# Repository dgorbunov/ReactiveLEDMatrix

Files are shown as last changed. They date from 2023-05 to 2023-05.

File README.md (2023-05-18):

# Reactive LED Matrix
An expandable matrix of addressable WS2812B RGB LEDs, made interactive through an array of high-power infrared LEDs and phototransistors. Panels can be plugged into other panels for large array sizes, and can be externally controlled via an ESP32 and custom React app. Final Project for UMass Amherst CICS 256, Make: Physical Computing.

### Photos
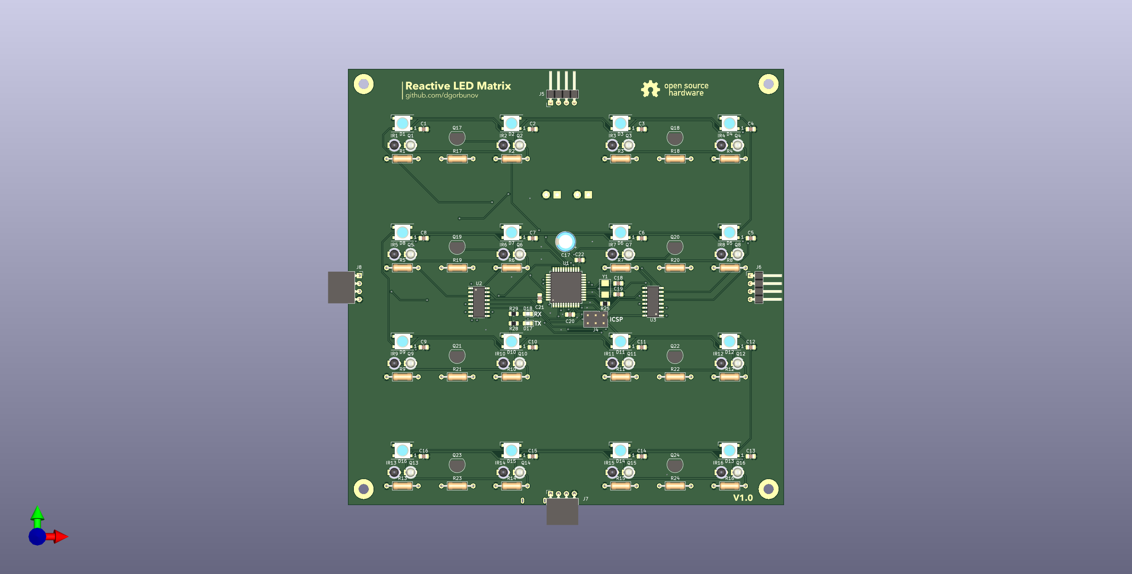
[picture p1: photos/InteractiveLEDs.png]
Board Render

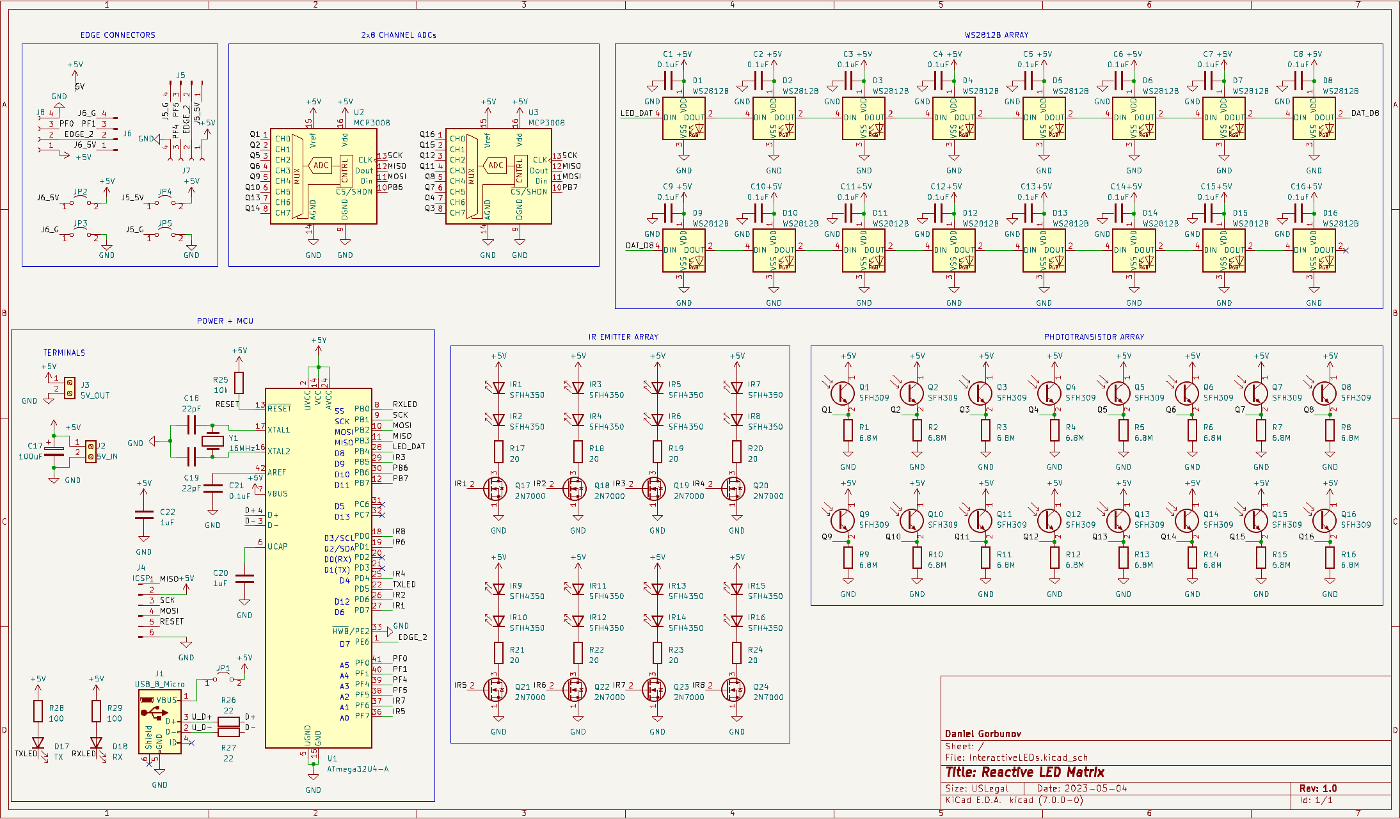
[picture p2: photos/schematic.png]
Schematic Image

## Hardware
Each panel is controlled by an ATMega32u4 microcontroller (compiling for Arduino Leonardo), along with two MCP3008 8 channel 10-bit ADCs for reading phototransistor voltages. The high-power infrared LEDs can sink up to 100mA, so each pair of IR LEDs is switched on through an N-Channel MOSFET for several microseconds and corresponding phototransistor output read. The edge connectors use UART to send data to up to four neighboring panels and thus propagate matrix effects across multiple panels.

Each tile of the matrix measures 140mm x 140mm with 35mm pitch between the WS2812B LEDs and 130mm between the mounting holes, which are M3.

### Build it Yourself
The BOM, Schematic, and Gerbers can be found [here](https://github.com/dgorbunov/ReactiveLEDMatrix/tree/main/hardware).
The DigiKey parts list can be found [here](https://www.digikey.com/en/mylists/list/SEOYTBGGIW)

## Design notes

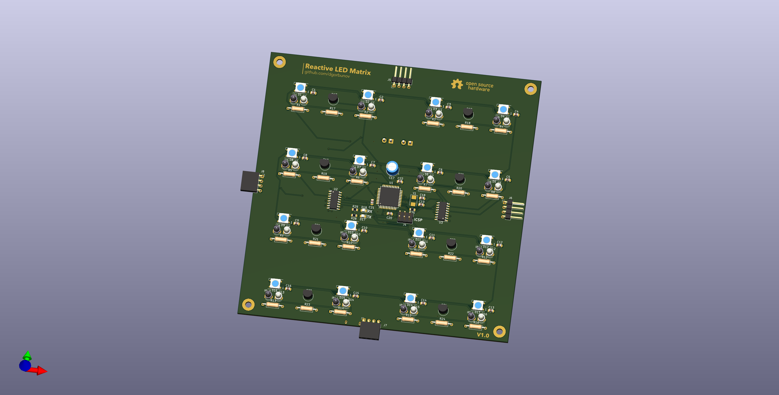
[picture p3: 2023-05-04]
photos/InteractiveLEDsSide.png

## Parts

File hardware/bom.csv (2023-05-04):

Comment | Designator | Footprint | LCSC
0.1uF | C1,C2,C3,C4,C5,C6,C7,C8,C9,C10,C11,C12,C13,C14,C15,C16,C21 | Capacitor_SMD:C_0805_2012Metric_Pad1.18x1.45mm_HandSolder
100uF | C17 | Capacitor_THT:CP_Radial_D6.3mm_P2.50mm
22pF | C18,C19 | Capacitor_SMD:C_0805_2012Metric_Pad1.18x1.45mm_HandSolder
1uF | C20,C22 | Capacitor_SMD:C_0805_2012Metric_Pad1.18x1.45mm_HandSolder
WS2812B | D1,D2,D3,D4,D5,D6,D7,D8,D9,D10,D11,D12,D13,D14,D15,D16 | LED_SMD:LED_WS2812B_PLCC4_5.0x5.0mm_P3.2mm
TX | D17 | LED_SMD:LED_0805_2012Metric_Pad1.15x1.40mm_HandSolder
RX | D18 | LED_SMD:LED_0805_2012Metric_Pad1.15x1.40mm_HandSolder
SFH4350 | IR1,IR2,IR3,IR4,IR5,IR6,IR7,IR8,IR9,IR10,IR11,IR12,IR13,IR14,IR15,IR16 | LED_THT:LED_D3.0mm_IRGrey
USB_B_Micro | J1 | Connector_USB:USB_Micro-B_GCT_USB3076-30-A
5V_IN | J2 | TerminalBlock_Phoenix:TerminalBlock_Phoenix_PT-1,5-2-3.5-H_1x02_P3.50mm_Horizontal
5V_OUT | J3 | TerminalBlock_Phoenix:TerminalBlock_Phoenix_PT-1,5-2-3.5-H_1x02_P3.50mm_Horizontal
ICSP | J4 | Connector_PinHeader_2.54mm:PinHeader_2x03_P2.54mm_Vertical
Conn_01x04_Pin | J5,J6 | Connector_PinHeader_2.54mm:PinHeader_1x04_P2.54mm_Horizontal
Conn_01x04_Socket | J7,J8 | Connector_PinSocket_2.54mm:PinSocket_1x04_P2.54mm_Horizontal
Jumper_2_Open | JP1,JP2,JP3,JP4,JP5 | Jumper:SolderJumper-2_P1.3mm_Open_TrianglePad1.0x1.5mm
SFH309 | Q1,Q2,Q3,Q4,Q5,Q6,Q7,Q8,Q9,Q10,Q11,Q12,Q13,Q14,Q15,Q16 | LED_THT:LED_D3.0mm_Clear
2N7000 | Q17,Q18,Q19,Q20,Q21,Q22,Q23,Q24 | Package_TO_SOT_THT:TO-92_Inline
10k | R1,R2,R3,R4,R5,R6,R7,R8,R9,R10,R11,R12,R13,R14,R15,R16 | Resistor_THT:R_Axial_DIN0207_L6.3mm_D2.5mm_P10.16mm_Horizontal
20 | R17,R18,R19,R20,R21,R22,R23,R24 | Resistor_THT:R_Axial_DIN0207_L6.3mm_D2.5mm_P10.16mm_Horizontal
10k | R25 | Resistor_SMD:R_0805_2012Metric_Pad1.20x1.40mm_HandSolder
22 | R26,R27 | Resistor_SMD:R_0805_2012Metric_Pad1.20x1.40mm_HandSolder
100 | R28,R29 | Resistor_SMD:R_0805_2012Metric_Pad1.20x1.40mm_HandSolder
ATmega32U4-A | U1 | Package_QFP:TQFP-44_10x10mm_P0.8mm
MCP3008 | U2,U3 | Package_SO:SOIC-16_3.9x9.9mm_P1.27mm
16MHz | Y1 | Crystal:Crystal_SMD_5032-2Pin_5.0x3.2mm

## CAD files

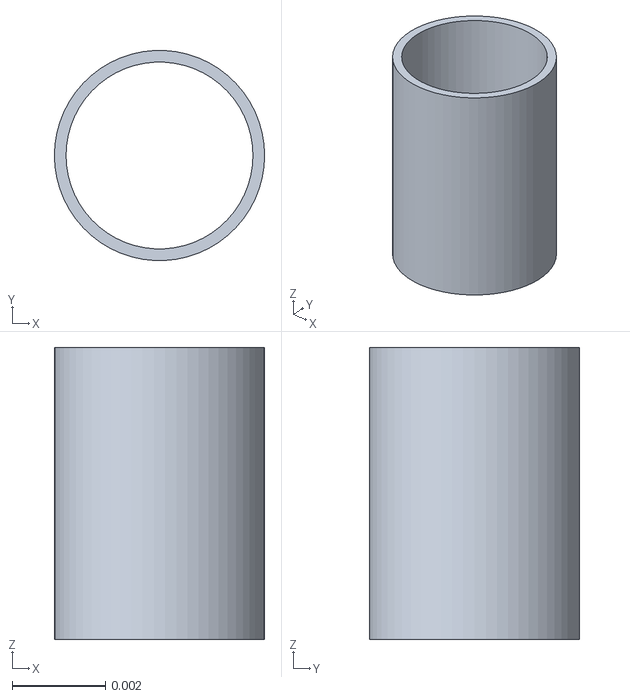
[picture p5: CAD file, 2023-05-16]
hardware/QShield.stl
0.0045 x 0.00449 x 0.00625

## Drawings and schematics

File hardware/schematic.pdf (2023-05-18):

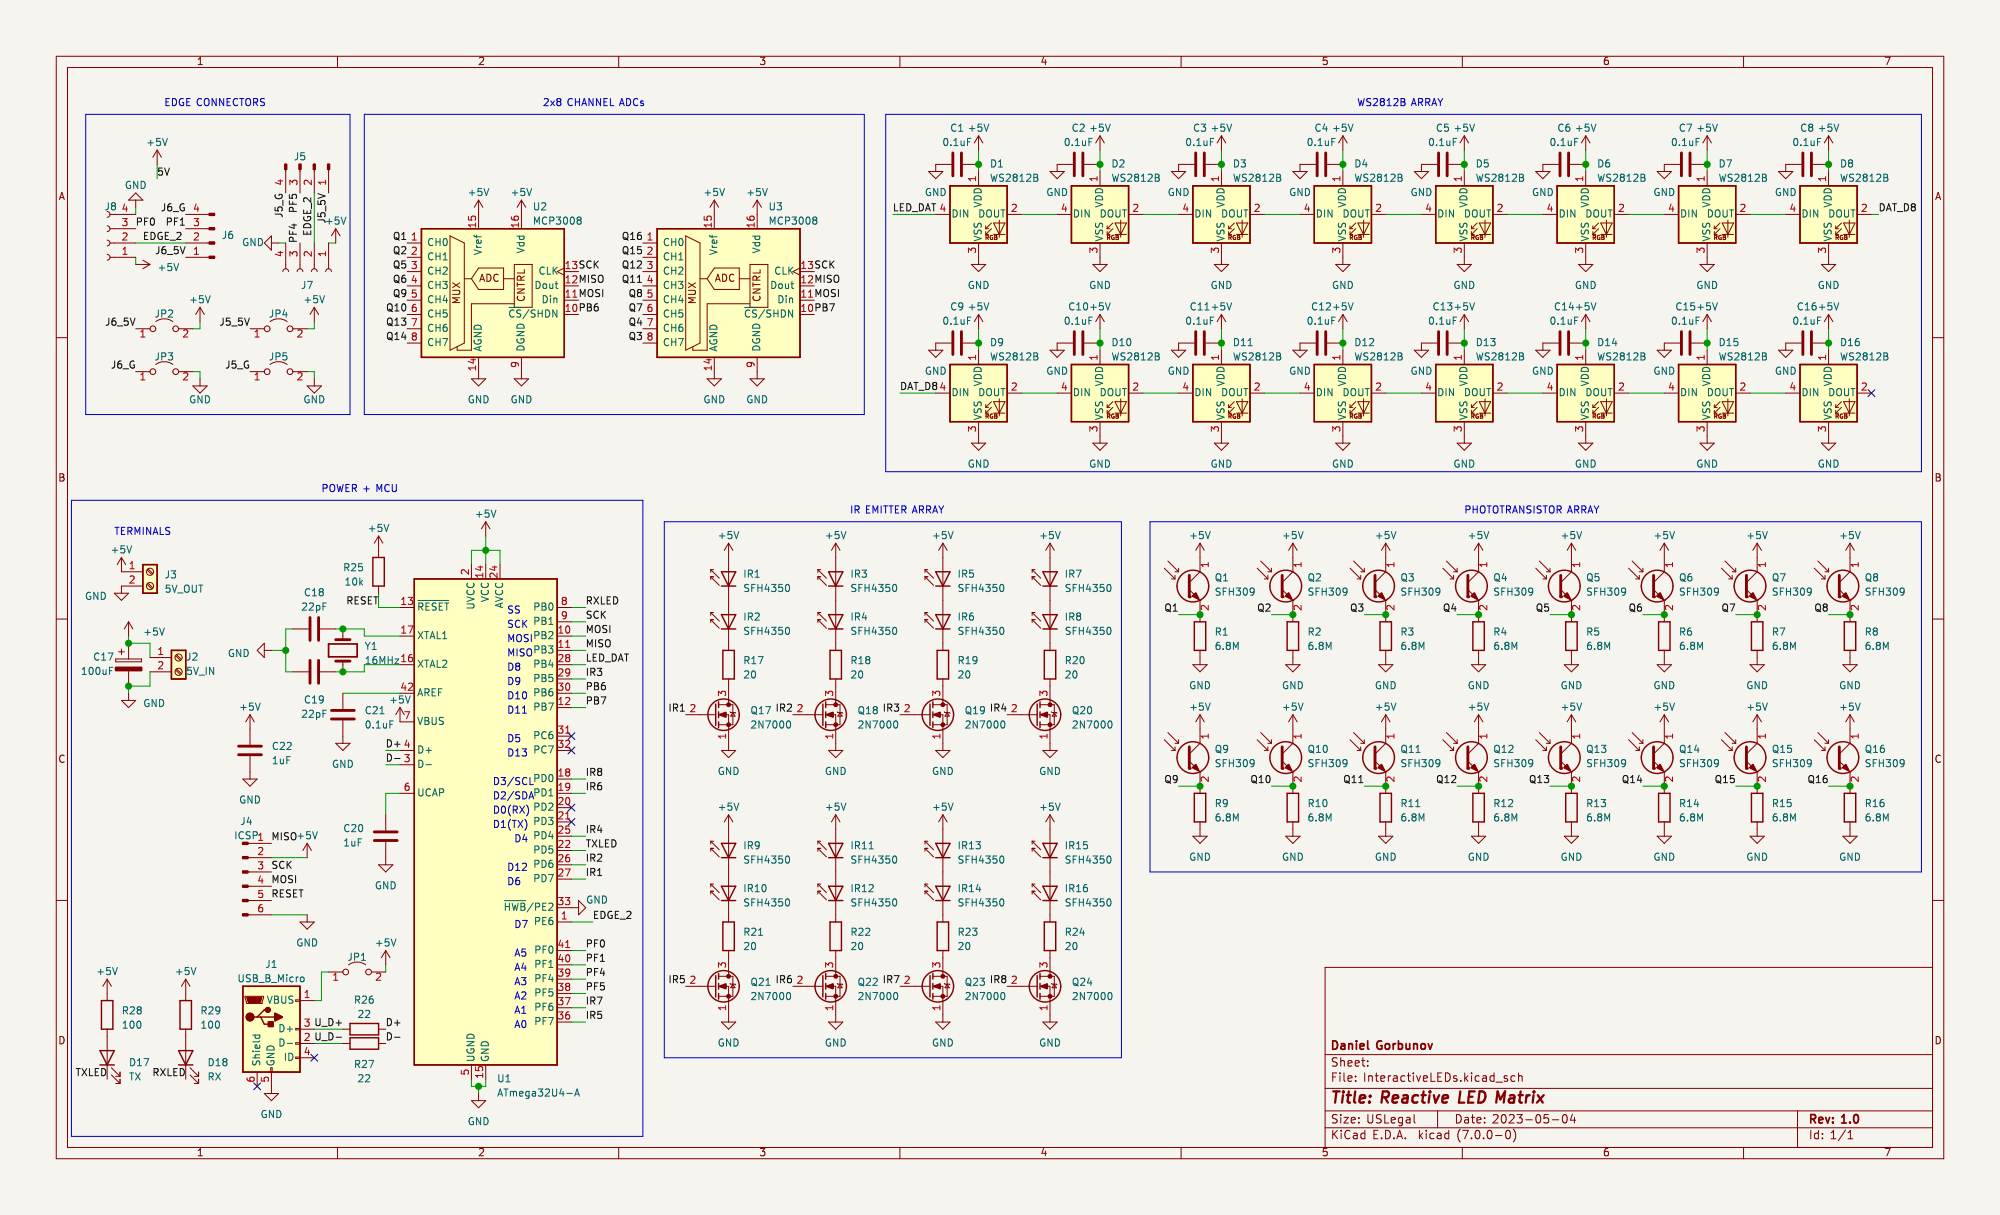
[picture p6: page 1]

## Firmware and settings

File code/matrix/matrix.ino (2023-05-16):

#include <FastLED.h>
#include <Adafruit_MCP3008.h>
#include <SoftwareSerial.h>
#include <MegunoLink.h>
#include <Filter.h>

// Pin definitions (fixed)
const int LED_DATA_PIN = 8;
const int IR_LED[8] = {6, 12, 9, 4, 18, 2, 19, 3};
const int ADC0_CS_PIN = 10;
const int ADC1_CS_PIN = 11;
const int EDGE_CLK = 7;
const int EDGE_DATA [2] = {19, 18}; // left, right

const int NUM_LEDS = 16;
const int BRIGHTNESS = 255;
CRGB leds[NUM_LEDS];

Adafruit_MCP3008 adc0;
Adafruit_MCP3008 adc1;

const int FILTER_WEIGHT = 60; // 0 -> full smoothing, 100 -> no smoothing
ExponentialFilter<long> * IRVals[16];
int IRThresholds[16];

const float NOISE_THRESHOLD = 1.40;

enum Mode {
  toggle = 0,
  distanceColor = 1,
  distanceBrightness = 2,
  distanceColorBrightness = 3,
  heatMap = 4,
  snake = 5,
  paint = 6,
  paintNeg = 7,
  paintBright = 8 
};

Mode currentMode = toggle;

void setup() { 
	Serial.begin(115200);

  for (int i = 0; i < 8; i++) {
    pinMode(IR_LED[i], OUTPUT);
  }

  // For data propogation
  pinMode(EDGE_CLK, INPUT);
  
	FastLED.addLeds<WS2812B,LED_DATA_PIN,GRB>(leds, NUM_LEDS);
	FastLED.setBrightness(BRIGHTNESS);

  adc0.begin(ADC0_CS_PIN);
  adc1.begin(ADC1_CS_PIN);

  for (int i = 0; i < 16; i++) {
    IRVals[i] = new ExponentialFilter<long>(FILTER_WEIGHT, 0);
  }

  calibrateIRThreshold();
}

unsigned long hueTimer = 0;
unsigned long brightTimer = 0;
unsigned long snakeTimer = 0;
void loop() { 
  static uint8_t hue = 0;

  readEdgeData();

	for(int i = 0; i < NUM_LEDS; i++) {
    // Account for LED sequence
    int index = i;
    if (i % 8 >= 4) {
      index = i > 11 ? 15 - i % 12 : 7 - i % 4;
    }

    if (IRVals[i]->Current() > IRThresholds[i]) {
      if (millis() - hueTimer > 10) {
        hueTimer = millis();
        hue++;
      }

      int value = 255 * (IRVals[i]->Current() - IRThresholds[i]) / (1023 - IRThresholds[i]);

      switch (currentMode) {
        case toggle:
          leds[index] = CHSV(hue, 255, 255);
          break;
        case distanceColor:
          leds[index] = CHSV(value, 255, 255);
          break;
        case distanceBrightness:
          leds[index] = CHSV(hue, 255, value);
          break;
        case distanceColorBrightness:
          leds[index] = CHSV(value, 255, value);
          break;
        case heatMap: 
          leds[index] = CHSV(90 - min((90 * value / 255) * 1.85, 90), 255, 255);
          break;
        case paint:
          leds[index] = CHSV(hue, 255, 255);
          break;
        case paintNeg:
          leds[index] = CHSV(hue, 255, 0);
          break;
        case paintBright:
          leds[index] = CHSV(hue, 255, 255-value);
          break;
      }
    }

    if (currentMode == snake){
      leds[(index + 1) % NUM_LEDS] = leds[index];
      delay(5);
    } 
	}

  if (currentMode != paint && currentMode != paintBright && currentMode != paintNeg){
    fadeLEDs();
  } else if (currentMode == paintBright || currentMode == paintNeg){
    if (millis() - brightTimer > 100) {
        brightTimer = millis();
        brightenLEDs(); 
      }
  }

  FastLED.show();
  
  for (int i = 0; i < 4; i ++) {
    captureIR(i, 0);
    captureIR(i, 1);
  }
}

void fadeLEDs() { 
  for(int i = 0; i < NUM_LEDS; i++) { 
    leds[i].nscale8(254.9); 
  } 
}

void brightenLEDs(){
  for(int i = 0; i < NUM_LEDS; i++) { 
    if (leds[i].red < 0.1 && leds[i].green < 0.1 & leds[i].blue < 0.1){
      leds[i].red = 1;
      leds[i].blue = 1;
      leds[i].green = 1;
    }
    else if (leds[i].red < 255 && leds[i].green < 255 && leds[i].blue < 255){
      leds[i].red += 1 + (255 - leds[i].red)/125;
      leds[i].blue += 1  + (255 - leds[i].red)/125;
      leds[i].green += 1  + (255 - leds[i].red)/125;
    }
  } 
}

void calibrateIRThreshold(){
  setFilterWeight(10);

  for (int i = 0; i < 4; i++) {
    setIR(i, 0);
    setIR(i, 1);   
  }

  for (int j = 0; j < 100; j++){
    for (int i = 0; i < 4; i ++) {
      captureIR(i, 0);
      captureIR(i, 1);
    }
  }

  // Serial.println("Calibration Results");
  for (int i = 0; i < NUM_LEDS; i++){
    IRThresholds[i] = IRVals[i]->Current() * NOISE_THRESHOLD;
    // Serial.println(i + " " + IRThresholds[i]);
  }

  setFilterWeight(FILTER_WEIGHT);
}

void setFilterWeight(int filterWeight) {
  for (int i = 0; i < 16; i++) {
    IRVals[i]->SetWeight(filterWeight);
  }
}

unsigned long dataTimer = 0;
boolean readingData = false;
const float pulseWidth = 50;

void readEdgeData() {
  int data = digitalRead(EDGE_CLK);

  if (data == 0 && !readingData) {
    dataTimer = millis();
    readingData = true;
  } else if (data == 1 && readingData) {
    unsigned long currentTime = millis();
    readingData = false;

    float result = (currentTime - dataTimer) / pulseWidth;
    if (result <= 1.5) {
      currentMode = paintBright;
    } else if (result <= 2.5) {
      currentMode = distanceColor;
    } else if (result <= 3.5) {
      currentMode = distanceBrightness;
    } else if (result <= 4.5) {
      currentMode = toggle;
    } else if (result <= 5.5) {
      currentMode = heatMap;
    } else if (result <= 7.5) {
      currentMode = paint;
    } else if (result <= 8.5){
      currentMode = paintNeg;
    }

    Serial.println(result);
    Serial.println(currentMode);
  }
}

void setIR(int index, int adc) {
  index *= 2;
  int offset = 2 * adc;

  IRVals[index * 2 + offset]->SetCurrent(readADC(index, adc));
  IRVals[index * 2 + 1 + offset]->SetCurrent(readADC(index + 1, adc));  
}

void captureIR(int index, int adc) {
  index *= 2;
  int offset = 2 * adc;

  digitalWrite(IR_LED[index + adc], HIGH);
  IRVals[index * 2 + offset]->Filter(readADC(index, adc));
  IRVals[index * 2 + 1 + offset]->Filter(readADC(index + 1, adc));
  digitalWrite(IR_LED[index + adc], LOW);
}

int readADC(int index, int adc) {
  return adc == 1 ? adc1.readADC(7 - index) : adc0.readADC(index);
}

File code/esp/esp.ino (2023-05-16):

#include <FirebaseESP32.h>
#include <WiFi.h>
#include "config.h"

#define TX_PIN 13

FirebaseData firebaseData;

int previousMode = -1;

void setup() {
  Serial.begin(9600);
  pinMode(TX_PIN, OUTPUT);
  pinMode(LED_BUILTIN, OUTPUT);

  digitalWrite(TX_PIN, HIGH);

  // connect to wifi.
  WiFi.begin(WIFI_SSID, WIFI_PASSWORD);
  Serial.print("Connecting");
  while (WiFi.status() != WL_CONNECTED) {
    Serial.print(".");
    delay(500);
  }
  Serial.println();
  Serial.print("Connected: ") ;
  Serial.println(WiFi.localIP());
  Firebase.begin(FIREBASE_HOST, FIREBASE_AUTH);
  Firebase.reconnectWiFi(true);     
}

void loop() {
  if (Firebase.getInt(firebaseData, "/Led1Mode")) {
    int data = firebaseData.intData();
    if (data != previousMode) {
      previousMode = data;
      // Serial.println("Sending: " + (String)data);
      sendPayload(data);
    }
  }
}

void sendPayload(int data) {
  int pulseWidth = 50;
  int intervals = data + 1;

  digitalWrite(LED_BUILTIN, HIGH);

  for (int i = 0; i < intervals; i++) {
    digitalWrite(TX_PIN, LOW);
    delay(pulseWidth);
  }

  digitalWrite(TX_PIN, HIGH);
  digitalWrite(LED_BUILTIN, LOW);
}

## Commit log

2023-05-04 Add bom and schematic
    [bom.csv]
2023-05-15 Add exponential filtering and fix mdoes
    [matrix.ino]
2023-05-16 Fix heatmap and improve noise removal
    [matrix.ino]
2023-05-16 Fix heatmap settings
2023-05-16 case statement, negpaint doesn't work
    [matrix.ino]
2023-05-16 Add qshield stl and test code
    [QShield.stl]
2023-05-16 paint neg still broken... might be a brightness issue
    [matrix.ino]
2023-05-18 Update resistor values, add ibom
2023-05-18 Add digikey link and fix schematic photo
